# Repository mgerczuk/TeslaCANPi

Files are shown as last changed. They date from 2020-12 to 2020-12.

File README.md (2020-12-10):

# TeslaCAN
Raspberry Pi Zero as CAN Logger for Tesla Model 3. The CAN data is stored offline on the Pi's SD card and can be pulled by a modifed TeslaLogger (https://github.com/bassmaster187/TeslaLogger). The data is the same (?) as the ScanMyTesla app uses.

The hardware consists of

- Raspberry Pi Zero
- Waveshare Pi Zero RS485 CAN HAT (https://www.waveshare.com/wiki/RS485_CAN_HAT)
- Pi Zero UPS Lite (https://github.com/linshuqin329/UPS-Lite)
- DS3231 RTC Shield
- Arduino Pro Mini ATMega328 3.3V 8MHz
- DC/DC Converter 14V -> 5V

The software consists of

- .net executable for Mono on Raspberry Pi running as a service
- Arduino sketch for ATMega328

## Installation

Connect the Pi with the CAN Hat, UPS, Arduino and RTC like described in the Fritzing file.

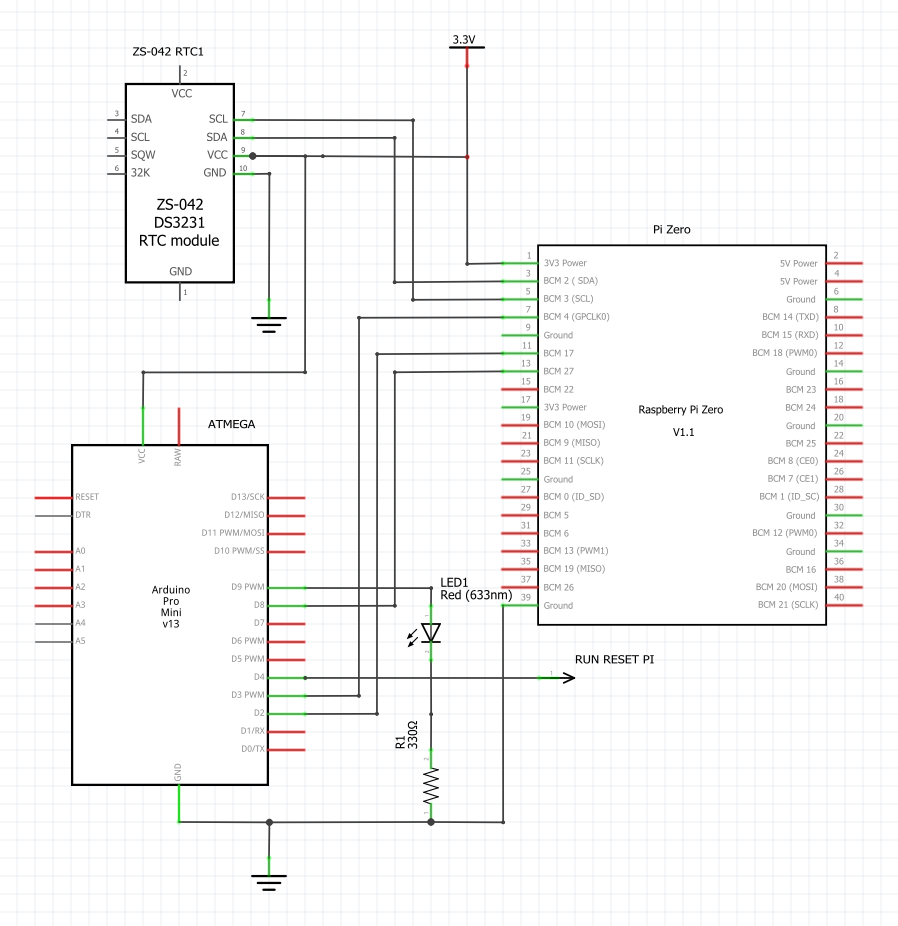
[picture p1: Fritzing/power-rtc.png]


### Install Raspbian

Create SD card with Raspbian 10 (buster). Install Mono like described at https://www.mono-project.com/download/stable/#download-lin-debian but using stable-raspbianbuster: 
```
sudo apt install apt-transport-https dirmngr gnupg ca-certificates
sudo apt-key adv --keyserver hkp://keyserver.ubuntu.com:80 --recv-keys 3FA7E0328081BFF6A14DA29AA6A19B38D3D831EF
echo "deb https://download.mono-project.com/repo/debian stable-raspbianbuster main" | sudo tee /etc/apt/sources.list.d/mono-official-stable.list
sudo apt update
```

Prepare startup/shutdown control, CAN HAT and RTC in /boot/config.txt. Pay attention to oscillator, older versions of the CAN HAT may use a different frequency:
```
dtparam=spi=on
dtoverlay=mcp2515-can0,oscillator=12000000,interrupt=25,spimaxfrequency=1000000

dtoverlay=gpio-poweroff,gpiopin=17,active_low="y"
dtoverlay=gpio-shutdown,gpio_pin=27

dtoverlay=i2c-rtc,ds3231
```

### Create Pi Software

Get the free Visual Studio Community Edition (or any other VS) and install the Mono Framework (https://www.mono-project.com/download/stable/). I don't know what's the proper way to tell Visual Studio about the Mono .net library location, I set the "Reference Paths" in TeslaCAN's and dbus-sharps's project properties to the Mono framework directory (e.g. C:\Program Files\Mono\lib\mono\4.6-api). Otherwise Visual Studio will report missing namespace 'Mono'.
Now compile TeslaCAN project. Copy the exe and dll files from the bin directory to /home/pi/TeslaCAN. Install Linux service by copying VisualStudio/Linux Service/TeslaCAN.service to /usr/lib/systemd/system/. Permanently install the service with
```
sudo systemctl enable TeslaCAN
```

In case you want to debug code on the Pi have a look at VSMonoDebugger. This works almost as nice as debugging on a PC!

### Create Arduino Software

Compile and flash Arduino/raspi_power.ino to the Arduino Pro Mini.

## How It Looks

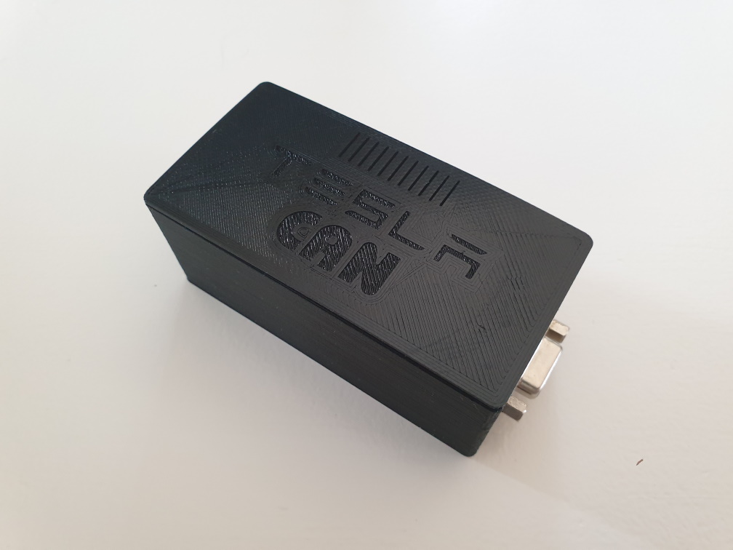
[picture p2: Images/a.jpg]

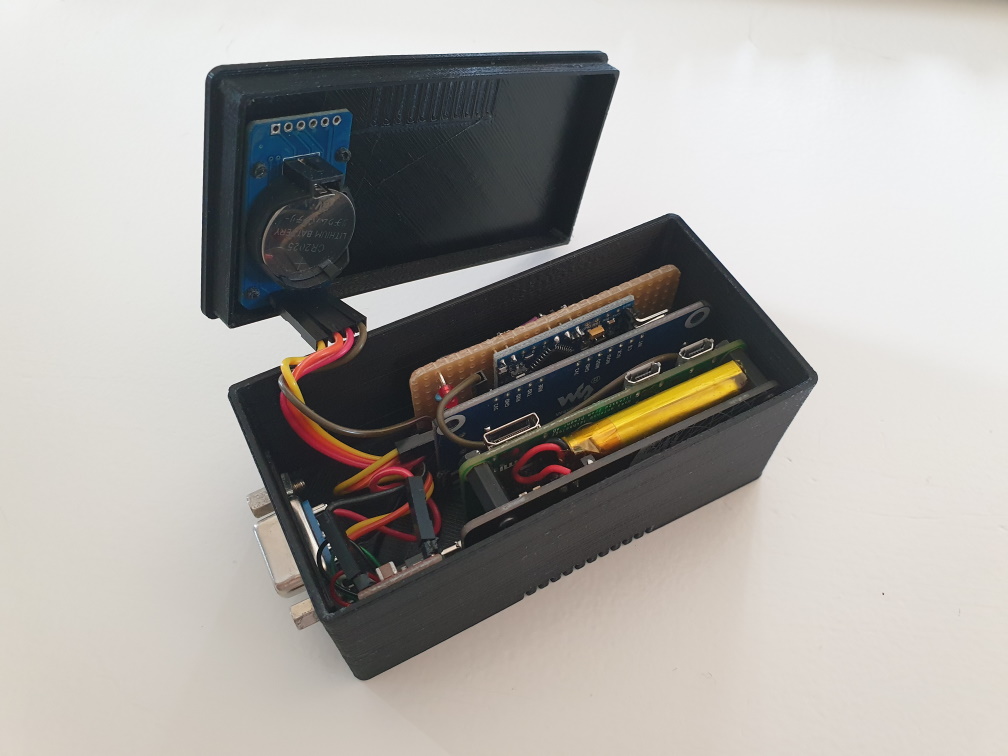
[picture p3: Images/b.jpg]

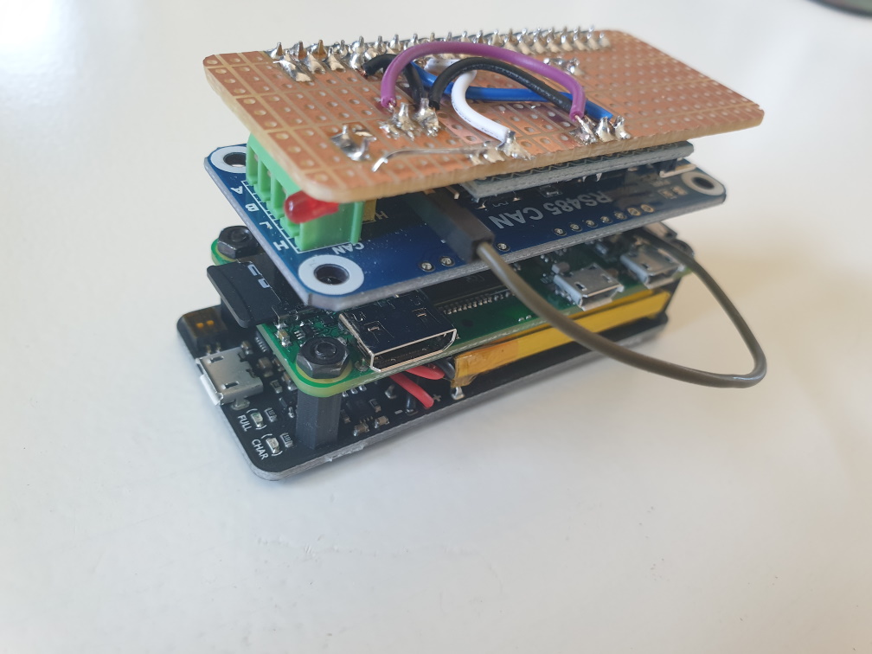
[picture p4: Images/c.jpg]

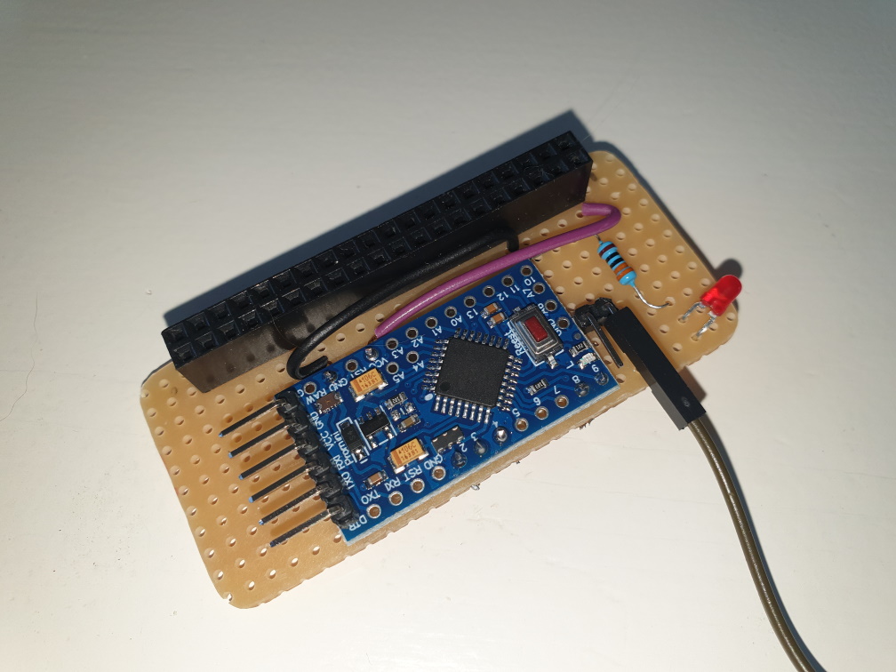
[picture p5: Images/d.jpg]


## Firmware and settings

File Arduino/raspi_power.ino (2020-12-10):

#include <avr/sleep.h>

int piPowerOnInd = 2;
int extPowerInd = 3;
int piReset = 4;
int piShutdownReq = 8;
int powerLed = 9;

void setup()
{
  pinMode(piPowerOnInd, INPUT);
  pinMode(extPowerInd, INPUT);

  digitalWrite(piReset, digitalRead(piPowerOnInd));
  pinMode(piReset, OUTPUT);

  digitalWrite(powerLed, digitalRead(piPowerOnInd));
  pinMode(powerLed, OUTPUT);

  digitalWrite(piShutdownReq, 1);
  pinMode(piShutdownReq, OUTPUT);

  Serial.begin(9600);
  Serial.println("Startup");
  delay(200);
    
  set_sleep_mode(SLEEP_MODE_PWR_DOWN);
  
  if (digitalRead(extPowerInd) == 0)
    switchPiOff();
  else
    switchPiOn();
}

// interrupt service routine in sleep mode
void piPowerIsr ()
{
  sleep_disable ();
  detachInterrupt (digitalPinToInterrupt (extPowerInd));
}

int waitForExtPower()
{
  noInterrupts ();
  sleep_enable ();    // enables the sleep bit in the mcucr register
  EIFR = bit (INTF1); // clear flag for interrupt 1
  attachInterrupt (digitalPinToInterrupt (extPowerInd), piPowerIsr, CHANGE);
  interrupts();
  sleep_mode ();      // here the device is actually put to sleep!!

  return digitalRead(extPowerInd);
}

void switchPiOn()
{
  Serial.println("switchPiOn");
  digitalWrite(piReset, 1);

  int ledValue = 0;
  while (digitalRead(piPowerOnInd) == 0)
  {
    delay(200);
    ledValue = !ledValue;
    digitalWrite(powerLed, ledValue);
  }
  digitalWrite(powerLed, 1);
  
  Serial.println("Pi is up!");
  delay(100);
}

void requestShutdown()
{
  digitalWrite(piShutdownReq, 0);
  delay(200);
  digitalWrite(piShutdownReq, 1);
}

void switchPiOff()
{
  Serial.println("switchPiOff");
  
  requestShutdown();
  
  int ledValue = 1;
  int count = 10;
  while (digitalRead(piPowerOnInd) == 1)
  {
    if (count-- == 0)
    {
      requestShutdown();
      count = 10;
    }
    else
      delay(200);
      
    ledValue = !ledValue;
    digitalWrite(powerLed, ledValue);

  }
  digitalWrite(powerLed, 0);
  
  Serial.println("Pi is down - reset = 0");
  digitalWrite(piReset, 0);
  delay(100);
}

void loop() 
{
  int oldPowerState;
  int extPowerState = waitForExtPower();
  do
  {
    if (extPowerState == 0)
    {
      switchPiOff();
    }
    else
    {
      switchPiOn();
    }
    oldPowerState = extPowerState;
    extPowerState = digitalRead(extPowerInd);
  } 
  while (oldPowerState != extPowerState);
}

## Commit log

2020-08-07 CAN Bus im "listen only" Modus
2020-12-10 Doku eingefügt
    [power-rtc.fzz]
